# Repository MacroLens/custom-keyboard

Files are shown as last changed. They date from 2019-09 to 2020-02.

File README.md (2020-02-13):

# custom-keyboard
A custom mechanical keyboard I am making from scratch. The PCB will have functionality for Bluetooth LE, an LED matrix and USB-C outputs. Based on the AVR micro-controller family.



Thanks to [PCBWAY](https://www.pcbway.com/) for sending me some prototypes!

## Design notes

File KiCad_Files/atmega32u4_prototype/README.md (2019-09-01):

This is a KiCad project folder with my original prototype. It uses some libraries it might not need and was based heavily on [ruiqimao's guide](https://github.com/ruiqimao/keyboard-pcb-guide/blob/master/README.md) with some minor tweaks.

*Note*
The diodes are on the wrong side and the footprint has no capability for LEDs.Which the future prototype will address.

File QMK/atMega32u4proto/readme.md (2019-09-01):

# atMega32u4proto

atMega32u4proto

Dylan's ProtoBoard, This uses the atmega32u4 as a controller and has only 2x2 matrix for testing.

Keyboard Maintainer: [Dylan Le](https://github.com/MacroLens)  
Hardware Supported: PCB being used is custom and made by me, atmega32u4 
Hardware Availability: links to where you can find this hardware

Make example for this keyboard (after setting up your build environment):

    make atMega32u4proto:default

See the [build environment setup](https://docs.qmk.fm/#/getting_started_build_tools) and the [make instructions](https://docs.qmk.fm/#/getting_started_make_guide) for more information. Brand new to QMK? Start with our [Complete Newbs Guide](https://docs.qmk.fm/#/newbs).

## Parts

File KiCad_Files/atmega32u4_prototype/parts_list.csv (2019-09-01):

Quantity | Part Number | Manufacturer Part Number
5 | ATMEGA32U4-AURCT-ND | ATMEGA32U4-AUR
2 | SER3686CT-ND | FA-238 16.0000MB-C3
10 | 399-1113-1-ND | C0805C220J5GACTU
10 | 311-1361-1-ND | CC0805ZRY5V9BB104
10 | 1276-6465-1-ND | CL21A475KQFNNNG
10 | A126352CT-ND | CRG0805F22R
10 | RMCF0805JT10K0CT-ND | RMCF0805JT10K0
10 | A126379CT-ND | CRG0805F5K1
10 | 1N4148WTPMSCT-ND | 1N4148W-TP
10 | EG2531CT-ND | TL3342F160QG/TR
5 | 12401610E4#2ACT-ND | 12401610E4#2A
10 | 311-1365-1-ND | CC0805KKX7R7BB105

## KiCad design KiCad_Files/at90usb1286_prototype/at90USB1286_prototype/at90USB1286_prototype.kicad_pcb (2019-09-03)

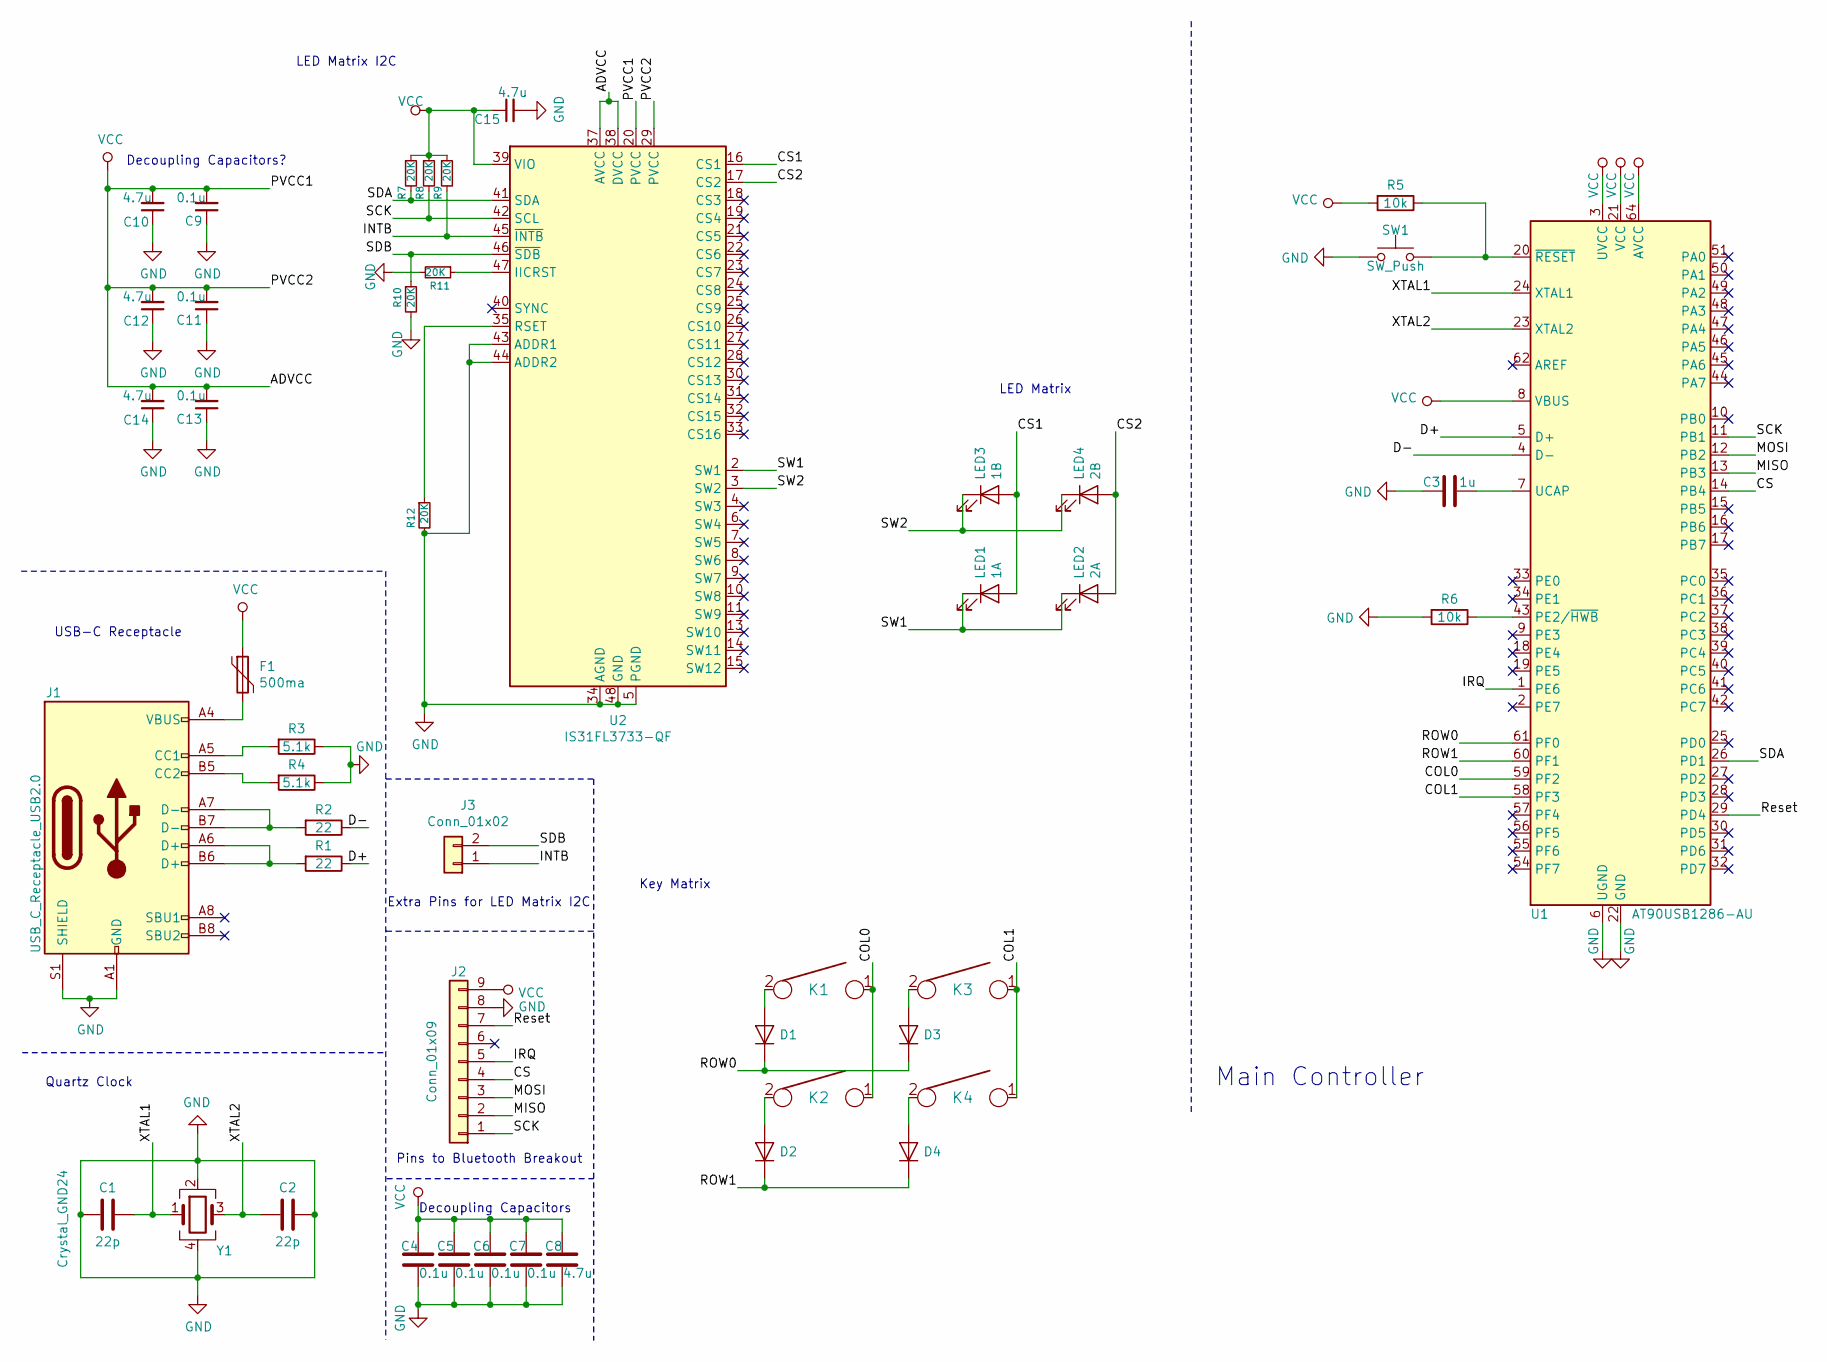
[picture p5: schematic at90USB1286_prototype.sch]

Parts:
C1, C2: 22p; C_0805_2012Metric_Pad1.15x1.40mm_HandSolder
C3: 1u; C_0805_2012Metric_Pad1.15x1.40mm_HandSolder
C4, C5, C6, C7, C9, C11, C13: 0.1u; C_0805_2012Metric_Pad1.15x1.40mm_HandSolder
C8, C10, C12, C14, C15: 4.7u; C_0805_2012Metric_Pad1.15x1.40mm_HandSolder
D1, D2, D3, D4: D; D_0805_2012Metric_Pad1.15x1.40mm_HandSolder
F1: 500ma; Fuse_0805_2012Metric_Pad1.15x1.40mm_HandSolder
J1: USB_C_Receptacle_USB2.0; USB_C_Receptacle_Amphenol_12401610E4-2A
J2: Conn_01x09; PinHeader_1x09_P1.27mm_Vertical
J3: Conn_01x02; PinHeader_1x02_P1.27mm_Vertical
K1, K2, K3, K4: KEYSW; MXOnly-1U-Hotswap
LED1: 1A; MXOnly-LEDONLY
LED2: 2A; MXOnly-LEDONLY
LED3: 1B; MXOnly-LEDONLY
LED4: 2B; MXOnly-LEDONLY
R1, R2: 22; R_0805_2012Metric_Pad1.15x1.40mm_HandSolder
R3, R4: 5.1k; R_0805_2012Metric_Pad1.15x1.40mm_HandSolder
R5, R6: 10k; R_0805_2012Metric_Pad1.15x1.40mm_HandSolder
R7, R8, R9, R10, R11, R12: 20K; R_0805_2012Metric_Pad1.15x1.40mm_HandSolder
SW1: SW_Push; SW_SPST_TL3342
U1: AT90USB1286-AU; TQFP-64_14x14mm_P0.8mm
U2: IS31FL3733-QF; QFN-48-1EP_6x6mm_P0.4mm_EP4.2x4.2mm
Y1: Crystal_GND24; Crystal_SMD_SeikoEpson_FA238V-4Pin_3.2x2.5mm

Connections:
/COL0: K1.1, K2.1, U1.59 (PF2)
/COL1: K3.1, K4.1, U1.58 (PF3)
/CS: J2.4, U1.14 (PB4)
/CS1: LED1.2 (A), LED3.2 (A), U2.16 (CS1)
/CS2: LED2.2 (A), LED4.2 (A), U2.17 (CS2)
/D+: R1.1, U1.5 (D+)
/D-: R2.1, U1.4 (D-)
/INTB: J3.1, R9.2, U2.45 (~INTB)
/IRQ: J2.5, U1.1 (PE6)
/MISO: J2.2, U1.13 (PB3)
/MOSI: J2.3, U1.12 (PB2)
/ROW0: D1.1 (K), D3.1 (K), U1.61 (PF0)
/ROW1: D2.1 (K), D4.1 (K), U1.60 (PF1)
/Reset: J2.7, U1.29 (PD4)
/SCK: J2.1, R8.2, U1.11 (PB1), U2.42 (SCL)
/SDA: R7.2, U1.26 (PD1), U2.41 (SDA)
/SDB: J3.2, R10.1, U2.46 (~SDB)
/SW1: LED1.1 (K), LED2.1 (K), U2.2 (SW1)
/SW2: LED3.1 (K), LED4.1 (K), U2.3 (SW2)
/XTAL1: C1.1, U1.24 (XTAL1), Y1.1
/XTAL2: C2.2, U1.23 (XTAL2), Y1.3
GND: C1.2, C2.1, C3.2, C4.2, C5.2, C6.2, C7.2, C8.2, C9.1, C10.1, C11.1, C12.1, C13.1, C14.1, C15.2, J1.A1 (GND), J1.A12 (GND), J1.B1 (GND), J1.B12 (GND), J1.S1 (SHIELD), J2.8, R3.1, R4.1, R6.2, R10.2, R11.2, R12.2, SW1.1, U1.6 (UGND), U1.22 (GND), U1.53 (GND), U1.63 (GND), U2.5 (PGND), U2.12 (PGND), U2.34 (AGND), U2.43 (ADDR1), U2.44 (ADDR2), U2.48 (GND), U2.49 (GND), Y1.2, Y1.4
unnamed: C3.1, U1.7 (UCAP)
unnamed: D1.2 (A), K1.2
unnamed: D2.2 (A), K2.2
unnamed: D3.2 (A), K3.2
unnamed: D4.2 (A), K4.2
unnamed: F1.2, J1.A4 (VBUS), J1.A9 (VBUS), J1.B4 (VBUS), J1.B9 (VBUS)
unnamed: J1.A5 (CC1), R3.2
unnamed: J1.A6 (D+), J1.B6 (D+), R1.2
unnamed: J1.A7 (D-), J1.B7 (D-), R2.2
unnamed: J1.B5 (CC2), R4.2
unnamed: R5.1, SW1.2, U1.20 (~RESET)
unnamed: R6.1, U1.43 (PE2/~HWB)
unnamed: R11.1, U2.47 (IICRST)
unnamed: R12.1, U2.35 (RSET)
VCC: C4.1, C5.1, C6.1, C7.1, C8.1, C9.2, C10.2, C11.2, C12.2, C13.2, C14.2, C15.1, F1.1, J2.9, R5.2, R7.1, R8.1, R9.1, U1.3 (UVCC), U1.8 (VBUS), U1.21 (VCC), U1.52 (VCC), U1.64 (AVCC), U2.20 (PVCC), U2.29 (PVCC), U2.37 (AVCC), U2.38 (DVCC), U2.39 (VIO)

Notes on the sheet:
Quartz Clock
Decoupling Capacitors
USB-C Receptacle
Pins to Bluetooth Breakout
Main Controller
LED Matrix I2C
LED Matrix
Extra Pins for LED Matrix I2C
Key Matrix
Decoupling Capacitors?

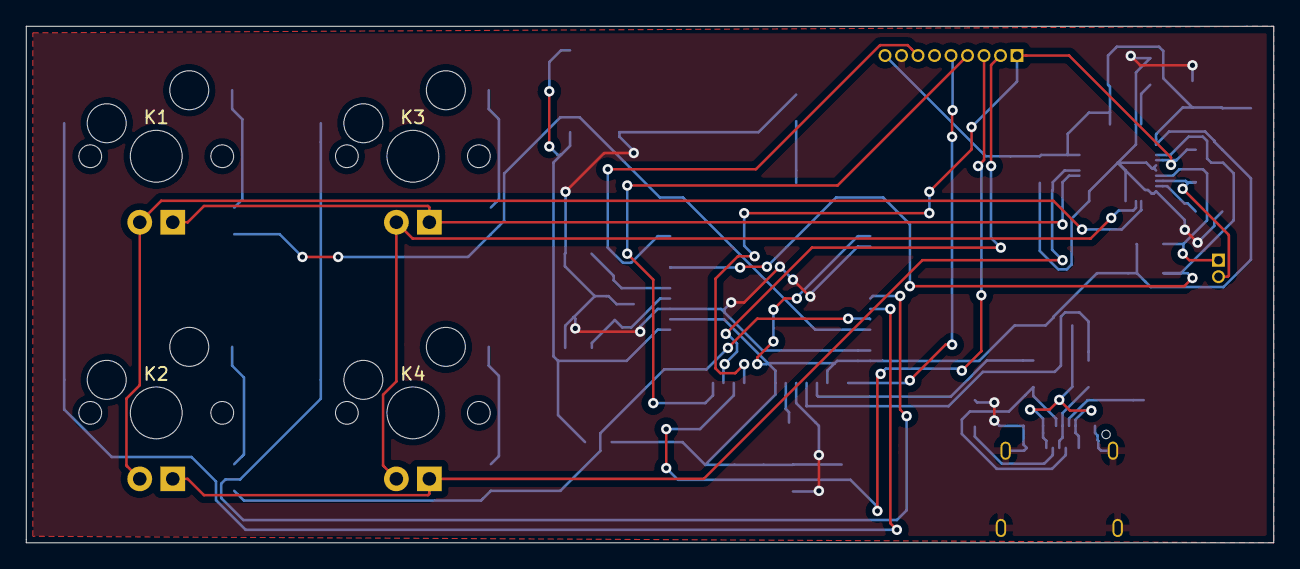
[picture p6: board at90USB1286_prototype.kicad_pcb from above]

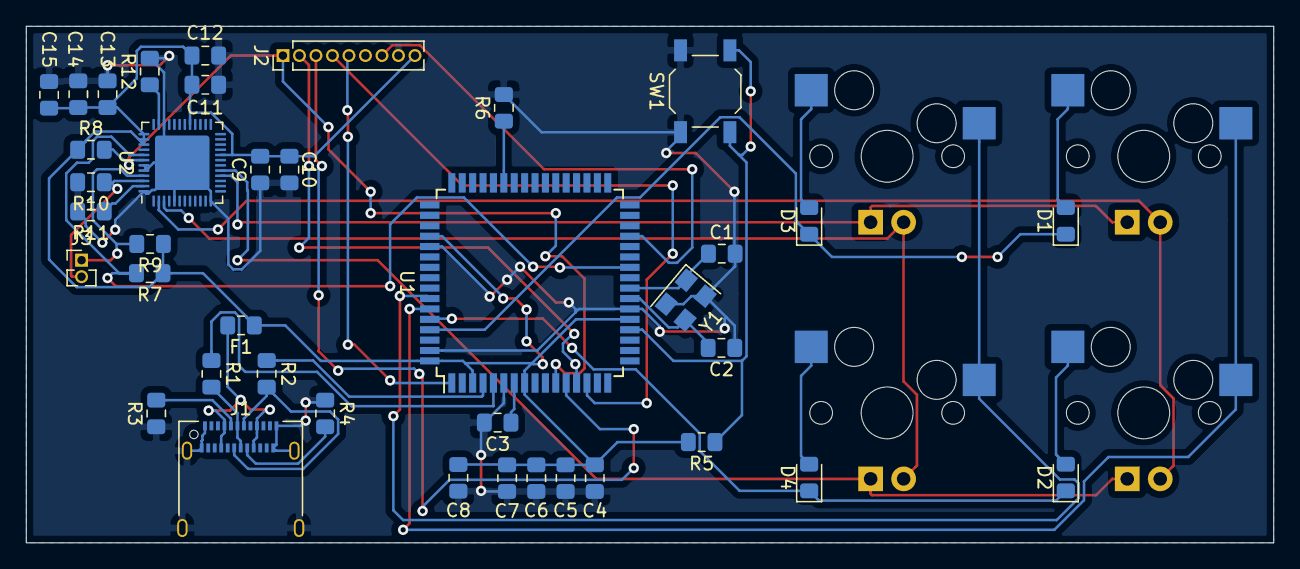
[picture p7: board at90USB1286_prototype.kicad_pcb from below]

Board: 2 copper layers, 96.0 x 39.8 mm, 47 parts (39 on the bottom side), 37 nets.

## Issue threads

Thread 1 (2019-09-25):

At90USB1286 board does not work with a fuse.

MacroLens, 2019-09-25:
If the connection is bridged without the reset fuse, everything is fine. Considering to just remove the fuse from the circuit.

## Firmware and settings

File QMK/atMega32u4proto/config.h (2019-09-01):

/*
Copyright 2019 Dylan Le

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
You should have received a copy of the GNU General Public License
along with this program.  If not, see <http://www.gnu.org/licenses/>.
*/ 

#pragma once

#include "config_common.h"

/* USB Device descriptor parameter */
#define VENDOR_ID 0xFEED
#define PRODUCT_ID 0x2571
#define DEVICE_VER 0x0001
#define MANUFACTURER Dylan Le
#define PRODUCT ProtoBoard
#define DESCRIPTION A prototype which uses the Atmega32u4 chip.

/* key matrix size */
#define MATRIX_ROWS 2
#define MATRIX_COLS 2

/*
 * Keyboard Matrix Assignments
 *
 * Change this to how you wired your keyboard
 * COLS: AVR pins used for columns, left to right
 * ROWS: AVR pins used for rows, top to bottom
 * DIODE_DIRECTION: COL2ROW = COL = Anode (+), ROW = Cathode (-, marked on diode)
 *                  ROW2COL = ROW = Anode (+), COL = Cathode (-, marked on diode)
 *
 */
#define MATRIX_ROW_PINS \
    { F0, F1 }
#define MATRIX_COL_PINS \
    { F4, F5 }
#define UNUSED_PINS

/* COL2ROW, ROW2COL*/
#define DIODE_DIRECTION COL2ROW

/*
 * Split Keyboard specific options, make sure you have 'SPLIT_KEYBOARD = yes' in your rules.mk, and define SOFT_SERIAL_PIN.
 */
#define SOFT_SERIAL_PIN D0  // or D1, D2, D3, E6

// #define BACKLIGHT_PIN B7
// #define BACKLIGHT_BREATHING
// #define BACKLIGHT_LEVELS 3

// #define RGB_DI_PIN E2
// #ifdef RGB_DI_PIN
//   #define RGBLED_NUM 16
//   #define RGBLIGHT_HUE_STEP 8
//   #define RGBLIGHT_SAT_STEP 8
//   #define RGBLIGHT_VAL_STEP 8
//   #define RGBLIGHT_LIMIT_VAL 255 /* The maximum brightness level */
//   #define RGBLIGHT_SLEEP  /* If defined, the RGB lighting will be switched off when the host goes to sleep */
// /*== all animations enable ==*/
//   #define RGBLIGHT_ANIMATIONS
// /*== or choose animations ==*/
//   #define RGBLIGHT_EFFECT_BREATHING
//   #define RGBLIGHT_EFFECT_RAINBOW_MOOD
//   #define RGBLIGHT_EFFECT_RAINBOW_SWIRL
//   #define RGBLIGHT_EFFECT_SNAKE
//   #define RGBLIGHT_EFFECT_KNIGHT
//   #define RGBLIGHT_EFFECT_CHRISTMAS
//   #define RGBLIGHT_EFFECT_STATIC_GRADIENT
//   #define RGBLIGHT_EFFECT_RGB_TEST
//   #define RGBLIGHT_EFFECT_ALTERNATING
// /*== customize breathing effect ==*/
//   /*==== (DEFAULT) use fixed table instead of exp() and sin() ====*/
//   #define RGBLIGHT_BREATHE_TABLE_SIZE 256      // 256(default) or 128 or 64
//   /*==== use exp() and sin() ====*/
//   #define RGBLIGHT_EFFECT_BREATHE_CENTER 1.85  // 1 to 2.7
//   #define RGBLIGHT_EFFECT_BREATHE_MAX    255   // 0 to 255
// #endif

/* Debounce reduces chatter (unintended double-presses) - set 0 if debouncing is not needed */
#define DEBOUNCE 5

/* define if matrix has ghost (lacks anti-ghosting diodes) */
//#define MATRIX_HAS_GHOST

/* Mechanical locking support. Use KC_LCAP, KC_LNUM or KC_LSCR instead in keymap */
#define LOCKING_SUPPORT_ENABLE
/* Locking resynchronize hack */
#define LOCKING_RESYNC_ENABLE

/* If defined, GRAVE_ESC will always act as ESC when CTRL is held.
 * This is userful for the Windows task manager shortcut (ctrl+shift+esc).
 */
// #define GRAVE_ESC_CTRL_OVERRIDE

/*
 * Force NKRO
 *
 * Force NKRO (nKey Rollover) to be enabled by default, regardless of the saved
 * state in the bootmagic EEPROM settings. (Note that NKRO must be enabled in the
 * makefile for this to work.)
 *
 * If forced on, NKRO can be disabled via magic key (default = LShift+RShift+N)
 * until the next keyboard reset.
 *
 * NKRO may prevent your keystrokes from being detected in the BIOS, but it is
 * fully operational during normal computer usage.
 *
 * For a less heavy-handed approach, enable NKRO via magic key (LShift+RShift+N)
 * or via bootmagic (hold SPACE+N while plugging in the keyboard). Once set by
 * bootmagic, NKRO mode will always be enabled until it is toggled again during a
 * power-up.
 *
 */
//#define FORCE_NKRO

/*
 * Magic Key Options
 *
 * Magic keys are hotkey commands that allow control over firmware functions of
 * the keyboard. They are best used in combination with the HID Listen program,
 * found here: https://www.pjrc.com/teensy/hid_listen.html
 *
 * The options below allow the magic key functionality to be changed. This is
 * useful if your keyboard/keypad is missing keys and you want magic key support.
 *
 */

/* key combination for magic key command */
/* defined by default; to change, uncomment and set to the combination you want */
// #define IS_COMMAND() (get_mods() == MOD_MASK_SHIFT)

/* control how magic key switches layers */
//#define MAGIC_KEY_SWITCH_LAYER_WITH_FKEYS  true
//#define MAGIC_KEY_SWITCH_LAYER_WITH_NKEYS  true
//#define MAGIC_KEY_SWITCH_LAYER_WITH_CUSTOM false
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

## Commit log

2019-09-01 The first board I made to test whether I could properly wire the chip and if the USB-C Port works.
    [first_keyboard-B_Cu.gbl, first_keyboard-B_Mask.gbs, first_keyboard-B_Paste.gbp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]
2019-09-01 Getting rid of old Gerber files which could be generated by anyone.
    [first_keyboard-B_Cu.gbl, first_keyboard-B_Mask.gbs, first_keyboard-B_Paste.gbp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]
2019-09-01 Old gerbers
2019-09-01 Replaced unarchived project with archived KiCad project.
    [first_keyboard.kicad_pcb, first_keyboard.sch]
2019-09-01 A parts list of all the components on the board. This can be uploaded to digikey for quick purchasing. There are extra components in the list just in case.
    [parts_list.csv]
2019-09-01 Added QMK files to be used with the AtMega32u4 prototype.
2019-09-02 New schematic with Bluetooth, LED matrix, and new chip.
    [at90USB1286_prototype.kicad_pcb, at90USB1286_prototype.sch, first_keyboard.kicad_pcb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]
2019-09-02 Working file removed
    [first_keyboard.kicad_pcb, first_keyboard.sch]
2019-09-03 Changed matrix I2C, and finished PCB
    [at90USB1286_prototype.kicad_pcb, at90USB1286_prototype.sch]

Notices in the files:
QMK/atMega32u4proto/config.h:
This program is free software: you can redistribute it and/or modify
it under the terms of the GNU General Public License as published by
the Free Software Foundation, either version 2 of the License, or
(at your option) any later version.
